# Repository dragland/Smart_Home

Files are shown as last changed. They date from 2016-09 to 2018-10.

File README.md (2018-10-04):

# Smart Home:
### A Home Automation system for the Raspberry Pi written in Python and JavaScript
[click here for a demo](https://htmlpreview.github.io/?https://github.com/dragland/Smart_Home/blob/master/html/index.html)

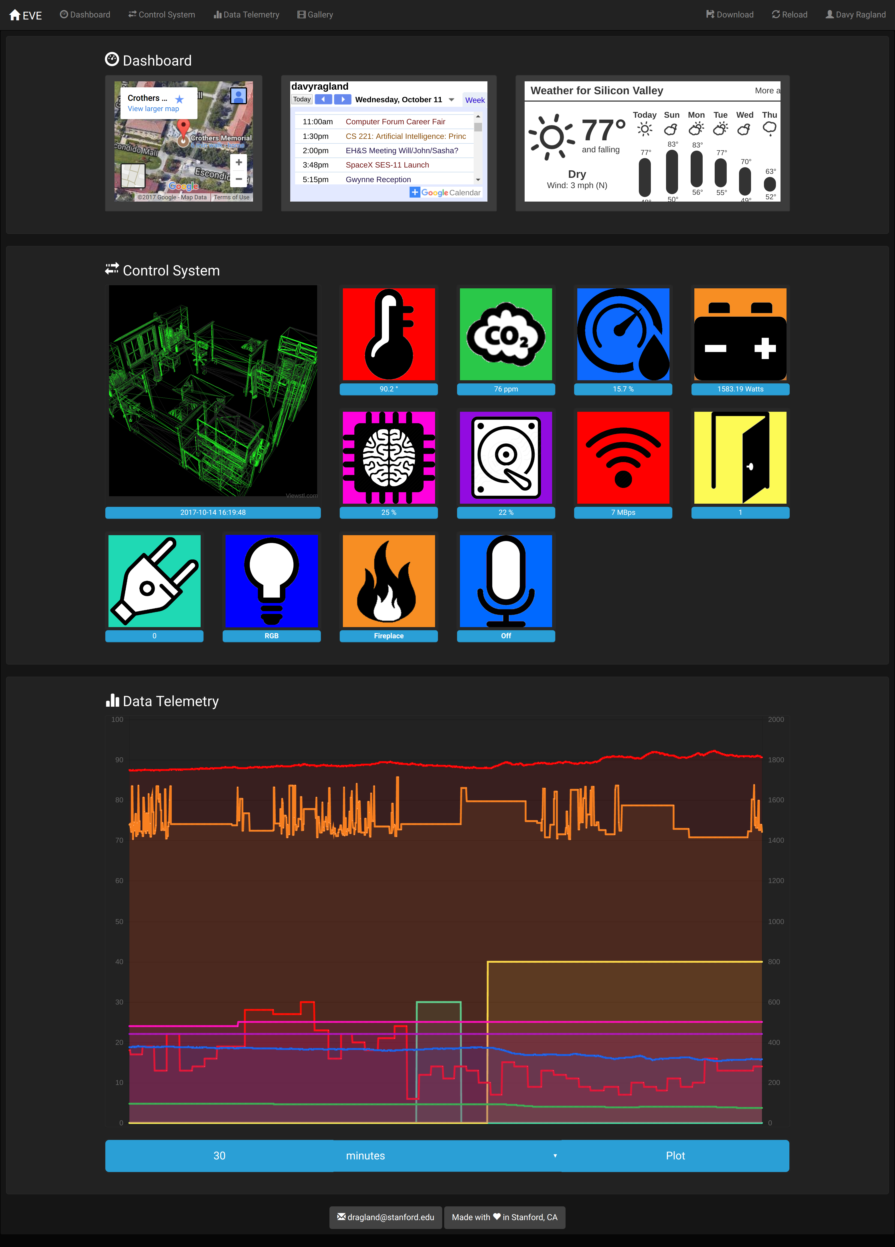
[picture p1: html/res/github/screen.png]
Smart_Home


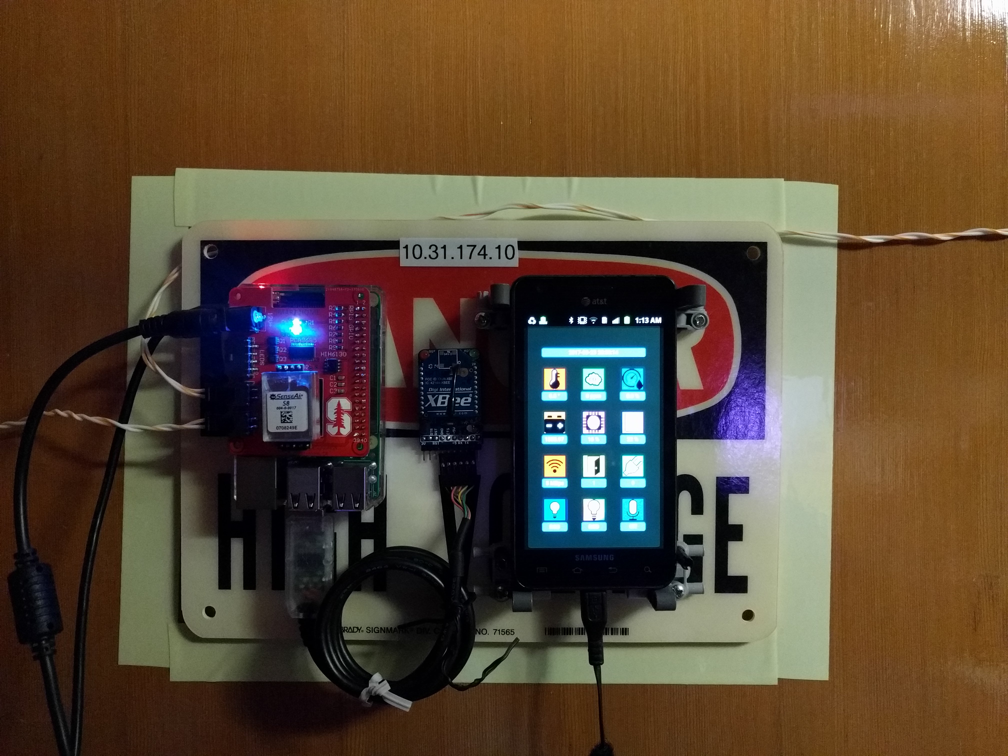
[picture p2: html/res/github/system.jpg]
Electronics


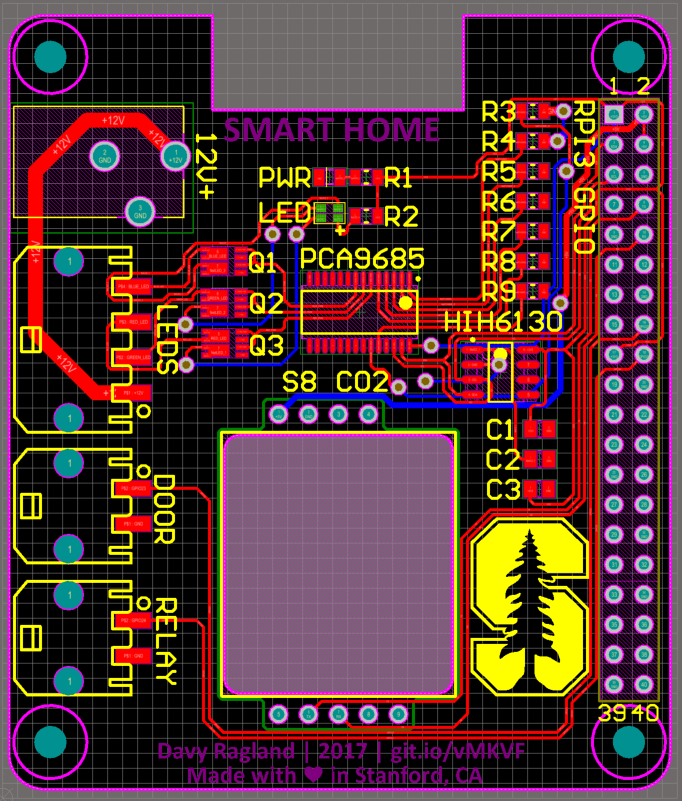
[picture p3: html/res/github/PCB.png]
Circuit Board


# Features:
1. Frontend web interface that shows live sensor readings
2. Frontend graphing utility to plot readings from SQL database
3. Frontend voice controls for interacting with system
4. Backend Python SQL logging script
5. Backend robust multithreaded architecture
2. Temperature and Humidity readings from HIH6130 sensor
2. CO2 readings from SenseAir S8 sensor
3. Power consumption readings from XBEE Tweet-A-Watt sensor
4. Door state readings from magnetic switch
5. Raspberry Pi system vitals readings from Linux
6. Remote control of Relay through web interface
7. Remote control of RGB LED strip through web interface

# Instalation:

```bash
cd /home/pi
curl "https://raw.githubusercontent.com/dragland/Smart_Home/master/install.sh" > install.sh
sudo chmod 755 install.sh
sudo ./install.sh
```

### You must manually setup the following:
##### Starting the script automatically:

```bash
sudo crontab -e
```

>@reboot /var/www/run.sh &

>0 12 * * * /sbin/shutdown -r now

##### Enabling CGI scripts:

```bash
sudo vim /etc/apache2/conf-available/serve-cgi-bin.conf
```

>ScriptAlias /cgi-bin/ /var/www/html/cgi-bin/

>&lt;Directory "/var/www/html/cgi-bin"&gt;

>	AddHandler cgi-script .py

>&lt;/Directory&gt;

##### Enabling Push notifications:

change the push variable inside keys.py to your pushbulet API KEY

# Schematics:
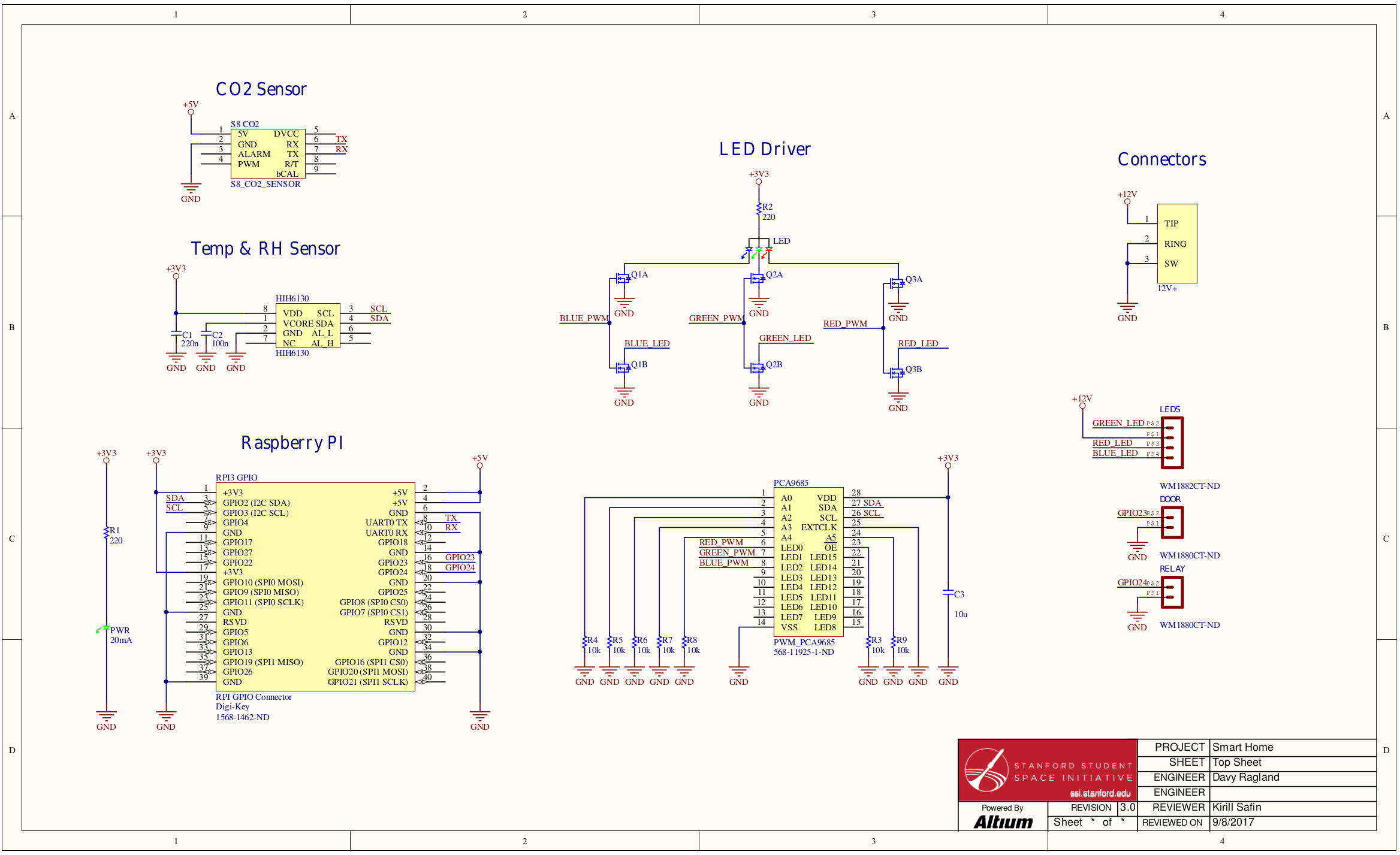
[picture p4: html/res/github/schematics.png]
Schematics


# Bill of Materials:
| Designator | Part ID |quantity |
| :--- | :--- | ---: |
| | RPI3 MODEL B | 1 |
| | P3 P4400 | 1 |
| | Tweet-a-Watt Kit | 1 |
| | | |
| C1 | 478-1400-1-ND | 1 |
| C2 | 478-3351-1-ND | 1 |
| C3 | 478-1417-1-ND | 1 |
| DOOR,RELAY | WM1880CT-ND | 2 |
| LEDS | WM1882CT-ND | 1 |
| PCA9685 | 568-11925-1-ND | 1 |
| R1,R2 | 541-220CCT-ND | 2 |
| R3,R4,R5,R6,R7,R8,R9 | 541-10.0KCCT-ND | 7 |
| 12V+ | CP-102A-ND | 1 |
| RPI3 GPIO | 1568-1462-ND | 1 |
| HIH6130 | 480-3651-1-ND | 1 |
| PWR | 475-1410-1-ND | 1 |
| LED | 160-2162-1-ND | 1 |
| Q1,Q2,Q3 | SI7232DN-T1-GE3CT-ND | 3 |
| S8 CO2 | SenseAir S8 | 1 |
| | | |
| | WM1847-ND | 1 |
| | WM1845-ND | 2 |
| | WM1839-ND | 8 |

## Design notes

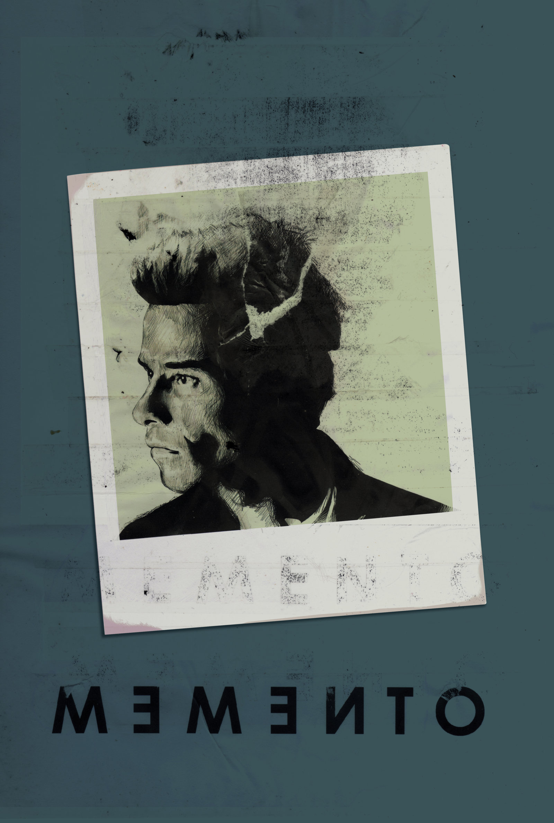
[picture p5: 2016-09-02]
html/res/posters/CmxkTHw.jpg

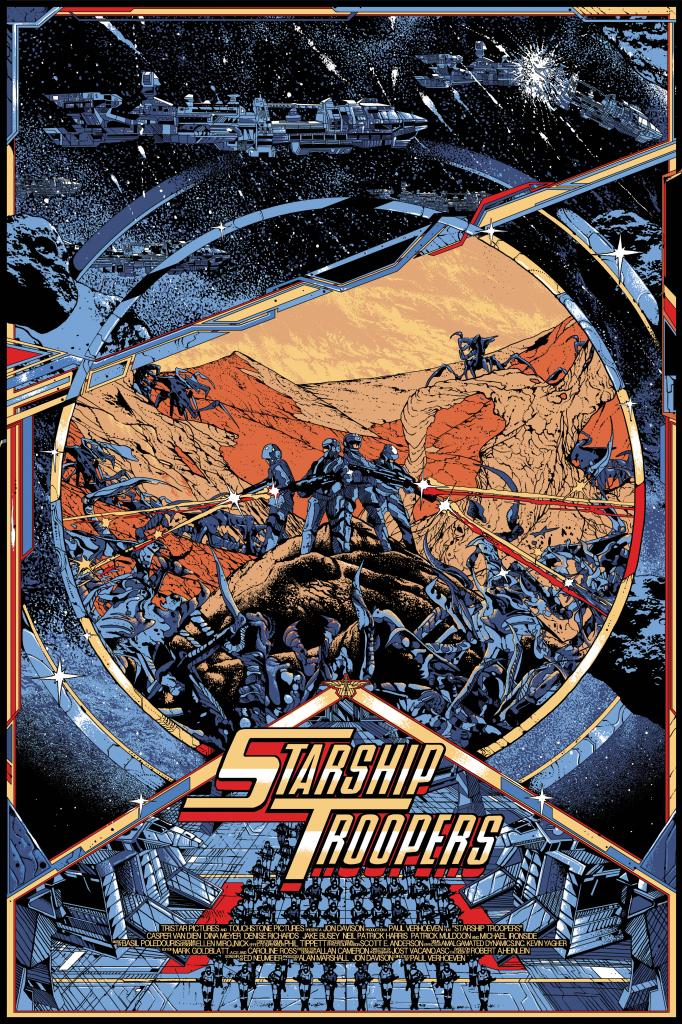
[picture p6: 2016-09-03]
html/res/posters/v0790aP.jpg

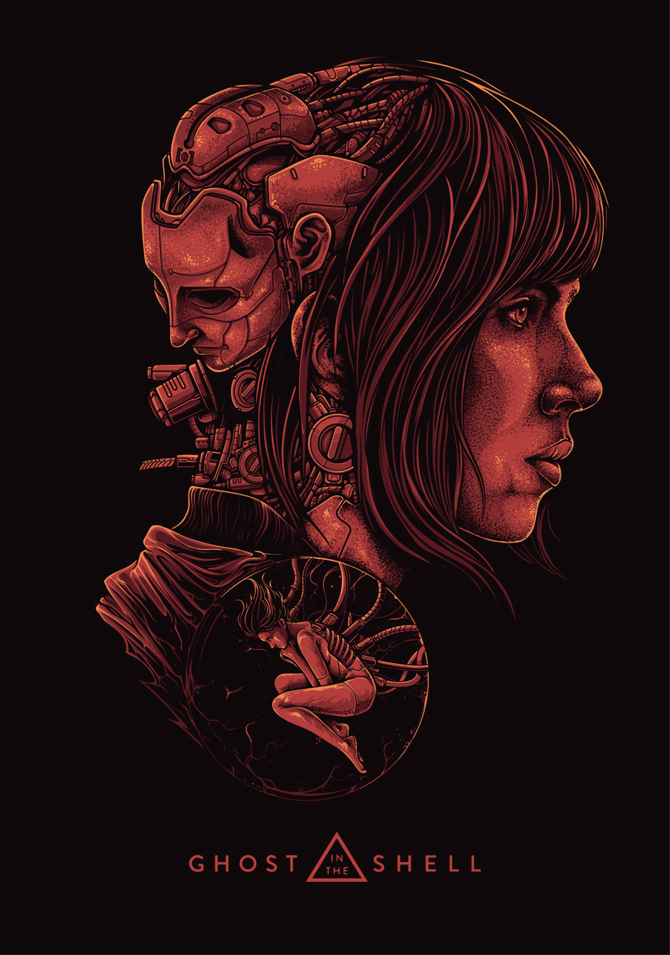
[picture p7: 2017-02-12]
html/res/posters/pyaa5an6fafy.jpg

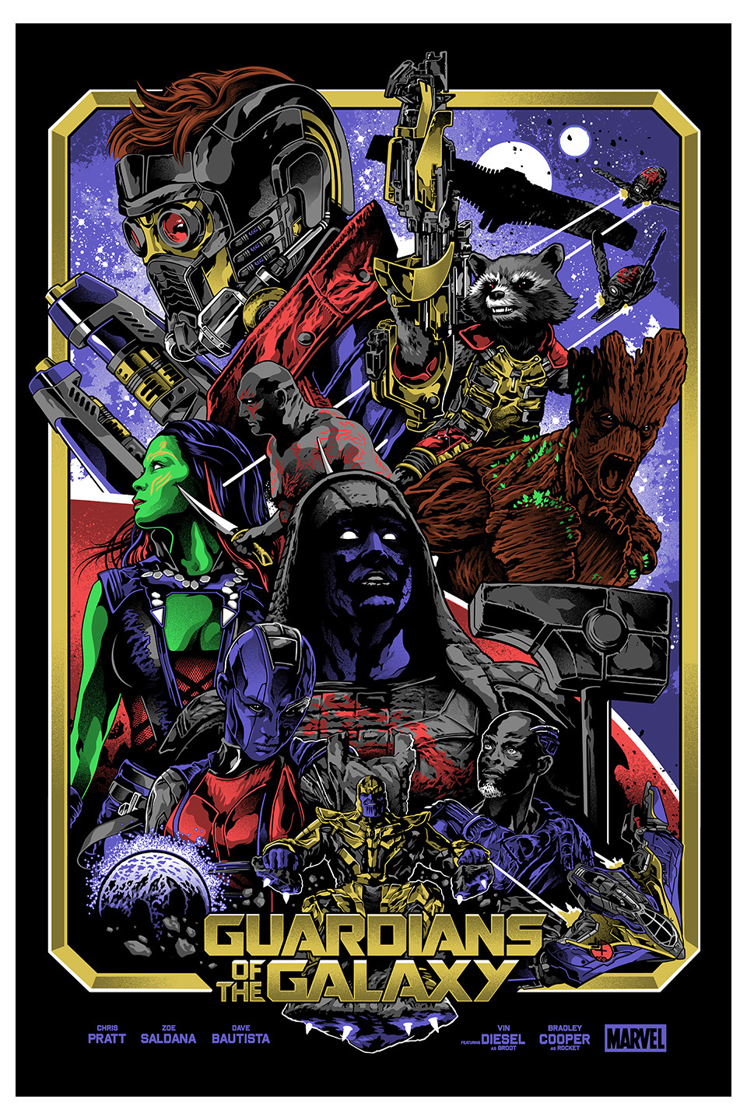
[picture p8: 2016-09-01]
html/res/posters/EcvJRqs.jpg

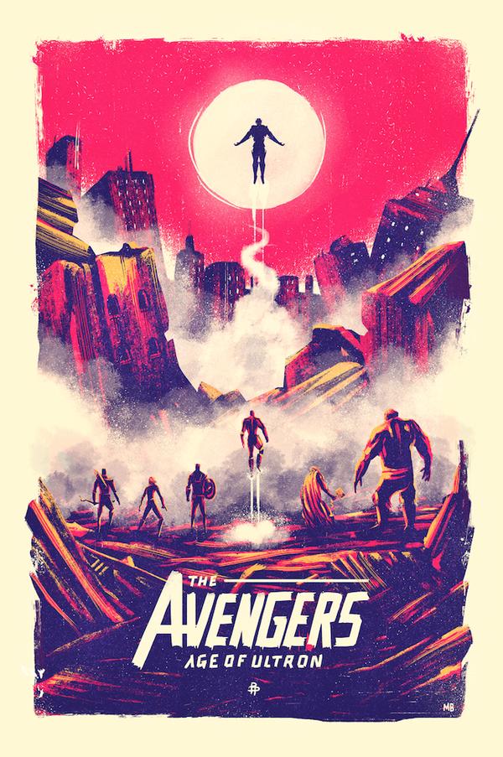
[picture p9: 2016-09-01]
html/res/posters/ZSCjdg3.jpg

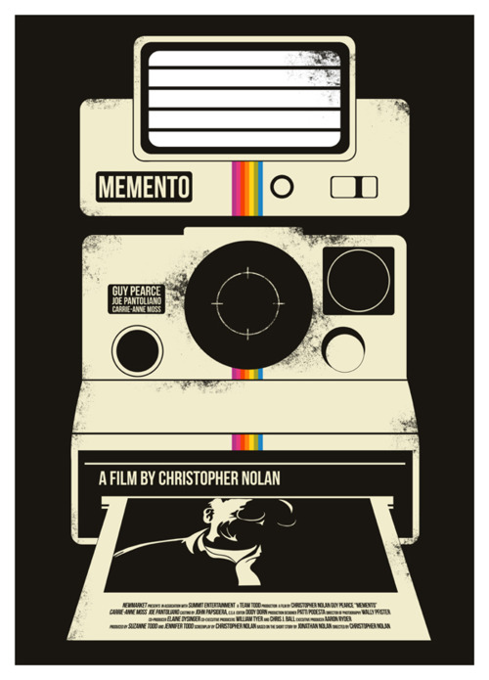
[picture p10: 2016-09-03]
html/res/posters/A9er26W.jpg

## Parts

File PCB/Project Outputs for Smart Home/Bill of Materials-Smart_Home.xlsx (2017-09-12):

Description | Designator | Footprint | Quantity | Supplier Part Number 1 | Manufacturer Part Number | Supplier Part Number | value | package | Package / Case
 | C1 | C0805 | 1 | 478-1400-1-ND |  |  | 2.2e-07 | 0805
 | C2 | C0805 | 1 | 478-3351-1-ND |  |  | 1e-07 | 0805
 | C3 | C0805 | 1 | 478-1417-1-ND |  |  | 1e-05 | 0805
 | DOOR, RELAY | 43650-0209 | 2 | WM1880CT-ND | 0436500209
 | LEDS | 43650-0409 | 1 | WM1882CT-ND | 0436500409
 | PCA9685 | 28TSSOP65 | 1 | 568-11925-1-ND | PCA9685PW,118 |  |  |  | 28-TSSOP (0.173", 4.40mm Width)
 | R1, R2 | R0805 | 2 | 541-220CCT-ND (https://octopart-clicks.com/click/altium?sku=71-CRCW0805-220-E3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) | CRCW0805220RFKEA | 541-220CCT-ND | 220 | 0805 (2012 Metric)
 | R3, R4, R5, R6, R7, R8, R9 | R0805 | 7 | 541-10.0KCCT-ND (https://octopart-clicks.com/click/altium?sku=71-CRCW0805-10K-E3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) | CRCW080510K0FKEA | 541-10.0KCCT-ND | 10k | 0805 (2012 Metric)
CONN JACK POWER 2.1MM PCB | 12V+ | CUI_21x55_BARREL | 1 | CP-102A-ND | PJ-102A
GPIO Header for Raspberry Pi A+/B+/Pi 2/Pi 3 - 2x20 | RPI3 GPIO | rpi | 1 | 1568-1462-ND | PRT-14017
Humidity Temperature Sensor 0 ~ 100% RH I²C ±4% RH 6s Surface Mount, [NoValue] | HIH6130, S8 CO2 | 8SOIC150, S8 CO2 SENSOR | 2
LED 0805 GREEN 20MA | PWR | 0805_Diode | 1 | 475-1410-1-ND | LG R971-KN-1 |  |  |  | 0805 (2012 Metric)
LED RGB DIFFUSED 0606 | LED | LED_LITEON_LTST-C19HE1WT | 1 | 160-2162-1-ND | LTST-C19HE1WT |  |  |  | 0606 (1616 Metric)
MOSFET 2N-CH 20V 25A PPAK 1212-8 | Q1, Q2, Q3 | POWERPAK_1212-8_DUAL | 3 | SI7232DN-T1-GE3CT-ND | SI7232DN-T1-GE3 |  |  |  | PowerPAK® 1212-8 Dual

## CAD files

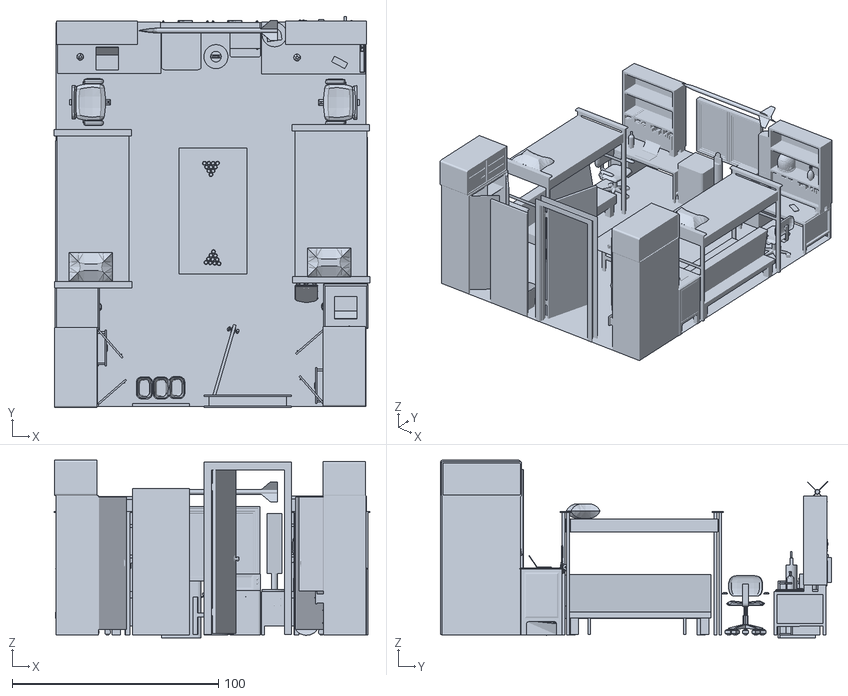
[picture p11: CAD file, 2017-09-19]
html/res/models/Smart_Home.stl
153.0 x 189.4 x 86.1

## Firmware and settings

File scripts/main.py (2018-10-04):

#!/usr/bin/env python
#Davy Ragland | dragland@stanford.edu
#Home Automation System version 4.0 | 2018

#*********************************** SETUP *************************************
import time
import threading
import smartHome

#**************************** Raspberry Pi Pinout ******************************
DOOR_PIN = 23
RELAY_PIN = 5

#************************************ MAIN *************************************
print("Executing program:")
smartHome.init_archive()
t1  = threading.Thread(target = smartHome.read_rh_temp)
t2  = threading.Thread(target = smartHome.read_co2)
t3  = threading.Thread(target = smartHome.read_energy)
t4  = threading.Thread(target = smartHome.read_cpu)
t5  = threading.Thread(target = smartHome.read_memory)
t6  = threading.Thread(target = smartHome.read_wifi)
t7  = threading.Thread(target = smartHome.read_door, args = (DOOR_PIN,))
t8  = threading.Thread(target = smartHome.read_relay, args = (RELAY_PIN,))
t1.start()
t2.start()
t3.start()
t4.start()
t5.start()
t6.start()
t7.start()
t8.start()
smartHome.init_relay(5)
smartHome.init_lights()
while True:
	if t1.is_alive() is False:
		del t1
		t1 = threading.Thread(target = smartHome.read_rh_temp)
		t1.start()
	if t2.is_alive() is False:
		del t2
		t2 = threading.Thread(target = smartHome.read_co2)
		t2.start()
	if t3.is_alive() is False:
		del t3
		t3 = threading.Thread(target = smartHome.read_energy)
		t3.start()
	if t4.is_alive() is False:
		del t4
		t4 = threading.Thread(target = smartHome.read_cpu)
		t4.start()
	if t5.is_alive() is False:
		del t5
		t5 = threading.Thread(target = smartHome.read_memory)
		t5.start()
	if t6.is_alive() is False:
		del t6
		t6 = threading.Thread(target = smartHome.read_wifi)
		t6.start()
	if t7.is_alive() is False:
		del t7
		t7 = threading.Thread(target = smartHome.read_door, args = (DOOR_PIN,))
		t7.start()
	if t8.is_alive() is False:
		del t8
		t8 = threading.Thread(target = smartHome.read_relay, args = (RELAY_PIN,))
		t8.start()
	smartHome.write_state()
	smartHome.write_archive()
	time.sleep(1)

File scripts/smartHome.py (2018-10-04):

#!/usr/bin/env python
#Davy Ragland | dragland@stanford.edu
#Home Automation System version 4.0 | 2018

#*********************************** SETUP *************************************
import os
import sys
import time
import smbus
import serial
import datetime
import subprocess
import sqlite3
import RPi.GPIO
import xbee
import state

#********************************* FUNCTIONS ***********************************
#Function: read_rh_temp
#This function reads the data from a HIH6130 humidity and temperature sensor.
def read_rh_temp():
	rh = 100
	temp_f = 256.98
	while ((rh == 100) or (temp_f == 256.98)):
		rh = 50
		temp_f = 60
		bus = smbus.SMBus(1)
		data = bus.read_i2c_block_data(0x27, 0x00, 4)
		rh = ((((data[0] & 0x3F) * 256) + data[1]) * 100.0) / 16383.0
		temp_f = ((((((data[2] & 0xFF) * 256) + (data[3] & 0xFC)) / 4) / 16384.0) * 165.0 - 40.0) * 1.8 + 32
		time.sleep(0.1)
	state.rh = rh
	state.temp_f = temp_f

#Function: read_co2
#This function reads the data from a SenseAir S8 CO2 sensor.
def read_co2():
	ser = serial.Serial("/dev/ttyS0",baudrate =9600,timeout = .5)
	ser.flushInput()
	ser.write("\xFE\x44\x00\x08\x02\x9F\x25")
	time.sleep(0.1)
	resp = ser.read(7)
	high = ord(resp[3])
	low = ord(resp[4])
	co2Value = (high*256) + low
	state.co2 = co2Value

#Function: read_energy
#This function reads the data from a Kill-A-Watt P3 sensor.
def read_energy():
	xb = xbee.XBee(serial.Serial("/dev/ttyUSB0", 9600))
	packet = xb.wait_read_frame()
	voltagedata = [-1] * (len(packet["samples"]) - 1)
	ampdata = [-1] * (len(packet["samples"]) - 1)
	for i in range(len(voltagedata)):
		voltagedata[i] = packet["samples"][i + 1]["adc-0"]
		ampdata[i] = packet["samples"][i + 1]["adc-0"]
	min_v = 1024
	max_v = 0
	for i in range(len(voltagedata)):
		if (min_v > voltagedata[i]):
			min_v = voltagedata[i]
		if (max_v < voltagedata[i]):
			max_v = voltagedata[i]
	avgv = (max_v + min_v) / 2
	vpp =  max_v - min_v
	for i in range(len(voltagedata)):
		voltagedata[i] -= avgv
		voltagedata[i] = (voltagedata[i] * 340) / vpp
	for i in range(len(ampdata)):
		ampdata[i] -= 470
		ampdata[i] /= 15.5
	wattdata = [0] * len(voltagedata)
	for i in range(len(wattdata)):
		wattdata[i] = voltagedata[i] * ampdata[i]
	avgamp = 0
	for i in range(17):
		avgamp += abs(ampdata[i])
	avgamp /= 17.0
	avgwatt = 0
	for i in range(17):
		avgwatt += abs(wattdata[i])
	avgwatt /= 17.0
	state.energy = avgwatt

#Function: read_cpu
#This function reads the percent memory used by the CPU.
def read_cpu():
	output = subprocess.check_output(["grep 'cpu ' /proc/stat | awk '{usage=($2+$4)*100/($2+$4+$5)} END {print usage}'"], shell=True)
	state.cpu = str(output)[:2]

#Function: read_memory
#This function reads the percent memory available on the raspberry pi.
def read_memory():
	output = subprocess.check_output(["df -h | grep /dev/root | cut -d ' ' -f 14-"], shell=True)
	state.memory = str(output)[:2]

#Function: read_wifi
#This function reads the wifi signal quality on the raspberry pi.
def read_wifi():
	output = subprocess.check_output(["speedtest-cli --csv --bytes | cut -d ',' -f 8 | cut -f1 -d '.' "], shell=True)
	state.wifi = str(int(output.rstrip('\n')) / 1000000)

#Function: read_door
#This function reads the data from a magnetic door sensor.
def read_door(PIN_NUMBER):
	RPi.GPIO.setmode(RPi.GPIO.BCM)
	RPi.GPIO.setup(PIN_NUMBER, RPi.GPIO.IN, pull_up_down = RPi.GPIO.PUD_UP)
	if RPi.GPIO.input(PIN_NUMBER):
		state.door = 1
	else:
		state.door = 0
	time.sleep(0.1)

#Function: read_relay
#This function reads the data from a relay.
def read_relay(PIN_NUMBER):
	if read_state(int(PIN_NUMBER)) == "1":
		state.relay = 1
	else:
		state.relay = 0
	time.sleep(0.1)

#Function: write_state
#This function prints and writes the current data from each sensor module to a state CSV.
def write_state():
	data = str("%s,%3.1f,%3.1f,%4.0f,%4.2f,%s,%s,%s,%d,%d" % (datetime.datetime.now().strftime("%Y-%m-%d %H:%M:%S"), state.temp_f, state.rh, state.co2, state.energy, state.cpu, state.memory, state.wifi, state.door, state.relay))
	stateFile = open("html/state", "w")
	stateFile.write(data + "\n")
	stateFile.close()
	print ">> System Status:",
	print data,
	sys.stdout.flush()
	print "\r",

#Function: write_archive
#This function writes the current data from each sensor module to a SQL database.
def write_archive():
	conn = sqlite3.connect("html/db/archive.db")
	curs = conn.cursor()
	curs.execute("INSERT INTO data values((?), (?), (?), (?), (?), (?), (?), (?), (?), (?))", (datetime.datetime.now().strftime("%Y-%m-%d %H:%M:%S"), "{0:.2f}".format(state.temp_f), "{0:.2f}".format(state.rh), "{0:.2f}".format(state.co2), "{0:.2f}".format(state.energy), state.cpu, state.memory, state.wifi, state.door, state.relay))
	conn.commit()
	conn.close()

#********************************** HELPERS ************************************
#Function: read_state
#This function reads the state of a relay.
def read_state(PIN_NUMBER):
	output = subprocess.check_output(["gpio read %i" % (PIN_NUMBER)], shell=True)
	return str(output)[:1]

#Function: init_relay
#This function initializes the relay to the default configuration.
def init_relay(PIN_NUMBER):
	os.system("gpio mode %i out" % (PIN_NUMBER))
	os.system("gpio write %i 0" % (PIN_NUMBER))

#Function: init_lights
#This function initializes the lights to the default configuration.
def init_lights():
	os.system("html/cgi-bin/RGB_Driver.py -r 0 0 -g 0 0 -b 0 4095")

#Function: init_archive
#This function initializes the SQL database.
def init_archive():
	conn = sqlite3.connect("html/db/archive.db")
	curs = conn.cursor()
	curs.execute("CREATE TABLE IF NOT EXISTS data (timestamp DATETIME, temp_f NUMERIC, rh NUMERIC, co2 NUMERIC, energy NUMERIC, cpu NUMERIC, memory NUMERIC, wifi NUMERIC, door INTEGER, relay INTEGER)")
	conn.commit()
	conn.close()

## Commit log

2016-09-03 Integrated DHT22 temp & humidity sensor.
2016-09-03 Added Door sensor.
2016-09-03 Threads question mark?
2016-09-03 JK I don't have an ADC.
2016-09-04 Implimented relay code.
2016-09-04 Enabled CGI scripts to control relay.
2016-09-05 Added another relay.
2016-09-05 Implimented fan.
2016-09-05 BCM vs WiringPi pinout.
2016-09-08 HTML won't print new lines, only breaks.
2016-09-08 Switched to datetime.
2016-09-10 Added automation function for relay control.
2016-09-10 Removed X axis labels.
2016-09-11 Used Buttons with HTML form to get inline justified interface for grapher.
2016-09-12 Escaping angle brakets.
2016-09-14 Added K-30 CO2 sensor.
2016-09-14 Why wont i2c Work
2016-09-14 Removed Co2 sensor.
2016-09-14 Added two more sensor values.
2016-09-15 Tried adding 2nd Y axis.
2016-09-15 Fingers crossed.
2016-09-15 Added fan.
2016-09-16 Expanded on LED controller.
2016-09-17 Added energy sensor.
2016-09-17 Added CO2 sensor.
2016-09-24 Fixed energy reading function.
    [smartHome.py]
2017-09-06 Integrated AN168-S8 CO2 sensor.
2017-09-08 Tested Door sensor and Relay.
2017-09-09 Completed PCB shematic and board.
2017-09-09 Added BOM.
2017-09-11 Added frontend RGB LED color picker interface.
2017-09-12 Added PCB files.
    [Bill of Materials-Smart_Home.xlsx, Smart_Home.PrjPcb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]
2017-09-13 Updated wifi sensor.
2017-09-13 Fixed relay bug.
2017-09-15 generalized out fan.
2017-09-19 Updated 3D model.
    [Smart_Home.stl]
2017-09-19 Decomposed out Pin numbers.
2017-09-19 Added HIH6130 sensor.
2017-10-01 Updated library for HIH6130 sensor.
2017-10-01 I think I fixed it.
    [smartHome.py]
2017-10-01 I hope this fixed it?
    [smartHome.py]
2017-10-01 Integrated LED controller.
2017-10-01 Damn you LEDs.
2017-10-22 Switched front end to not fine change.
2018-10-04 I actually fixed it now.
    [smartHome.py]
2018-10-04 Switching to sms.
2018-10-04 Mooved SMS block out to be just on reboot.
    [main.py, smartHome.py]
2018-10-04 Added debbuging prints.
2018-10-04 Handled appending case.
2020-08-27 fix: Update apartment stl
2020-08-27 fix: Compress apartment stl
2020-08-27 fix: Remove materials & rotate apartment stl
